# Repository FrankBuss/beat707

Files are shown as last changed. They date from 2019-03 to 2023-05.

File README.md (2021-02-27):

# Development environment

## Programmer and debug connection

For programming you can use an USBasp. The red wire of the USBasp programmer needs to be connected to the `pin 1` location:

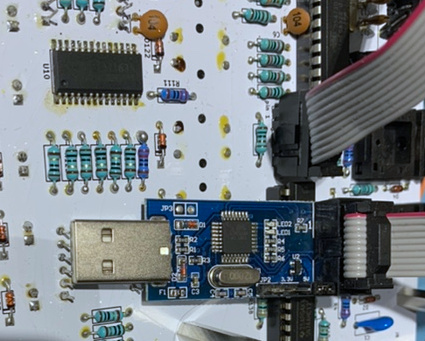
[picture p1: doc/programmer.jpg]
Programmer


For debugging, there is the jumper J5 near the MIDI connector, to connect a 5V UART receiver. Connect the top pin to GND (black wire in the image) and the bottom pin to the UART RX input (grey wire) :

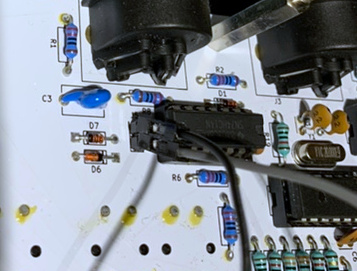
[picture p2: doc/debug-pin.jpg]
debug pin


## Fuse programming

The Arduino IDE doesn't flash the ATmega fuses, so initially you need to do this from the command line with avrdude like this:

```
avrdude -cusbasp -p m328 -B 10 -U lfuse:w:0xff:m
```
The output should look like this:

```
avrdude: set SCK frequency to 93750 Hz
avrdude: AVR device initialized and ready to accept instructions

Reading | ################################################## | 100% 0.00s

avrdude: Device signature = 0x1e9514 (probably m328)
avrdude: reading input file "0xff"
avrdude: writing lfuse (1 bytes):

Writing | ################################################## | 100% 0.00s

avrdude: 1 bytes of lfuse written
avrdude: verifying lfuse memory against 0xff:
avrdude: load data lfuse data from input file 0xff:
avrdude: input file 0xff contains 1 bytes
avrdude: reading on-chip lfuse data:

Reading | ################################################## | 100% 0.00s

avrdude: verifying ...
avrdude: 1 bytes of lfuse verified

avrdude: safemode: Fuses OK (E:FF, H:D9, L:FF)

avrdude done.  Thank you.
```

## Arduino IDE setup

First install the Arduino IDE. It was tested with Arduino 1.8.13. Then add the URL https://mcudude.github.io/MiniCore/package_MCUdude_MiniCore_index.json to "File->Preferences->Settings->Additional Board Manager URLs". Then you can install the new board with "Tools->Board->Boards Manager". Install "MiniCore by MCUdude", tested with version 2.1.0.

For programming you need an USBasp. You need to reduce the clock speed in the file `/home/username/bin/arduino-1.8.9/hardware/arduino/avr/programmers.txt`, where `username` is your username (on Linux, on Windows and Mac it might be different, see [here](https://www.arduino.cc/en/hacking/preferences)). Search for the `usbasp.program.extra_params` line and add the parameter `-B 10`. The full line now looks like this:

```
usbasp.program.extra_params=-Pusb -B 10
```

Restart the Arduino IDE after changing it.

After restart, select the new board: Tools->Board->MiniCore->ATmega328. For flashing the firmware, configure the following settings (Board, Clock, Variant and Bootloader needs to be changed):

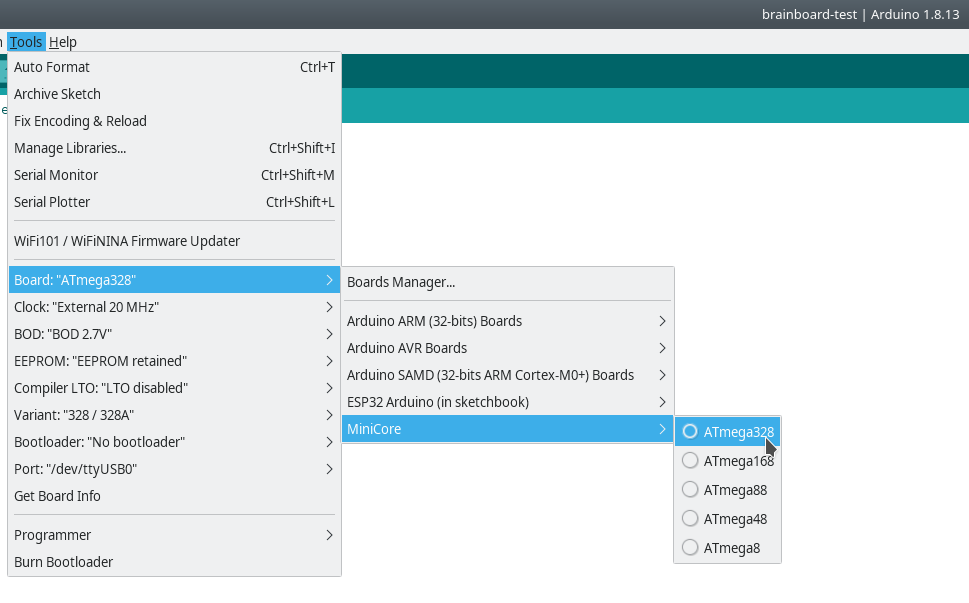
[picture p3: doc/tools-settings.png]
Arduino settings


Then select your programmer, for example USBasp:

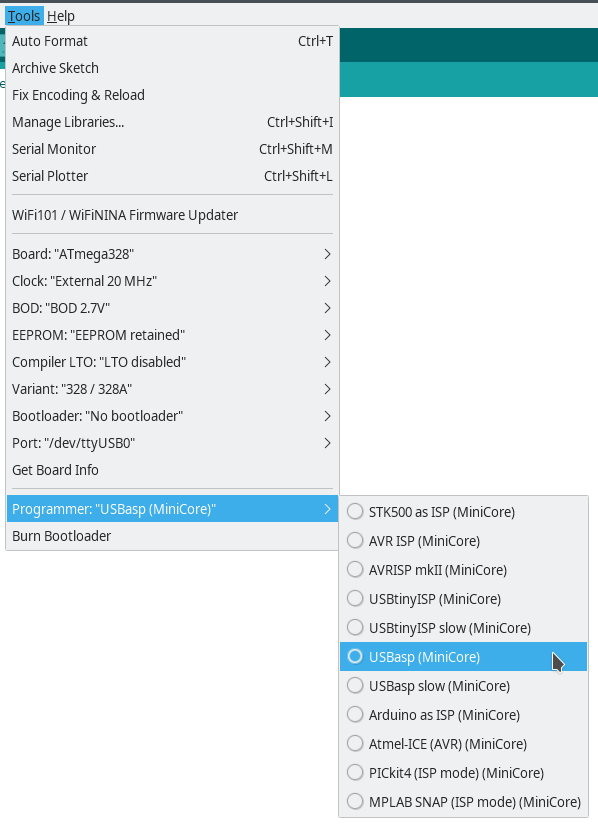
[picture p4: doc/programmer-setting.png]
Prorgammer settings


After this you can program the ATmega328 on the board from the Arduino IDE by clicking on the right arrow.

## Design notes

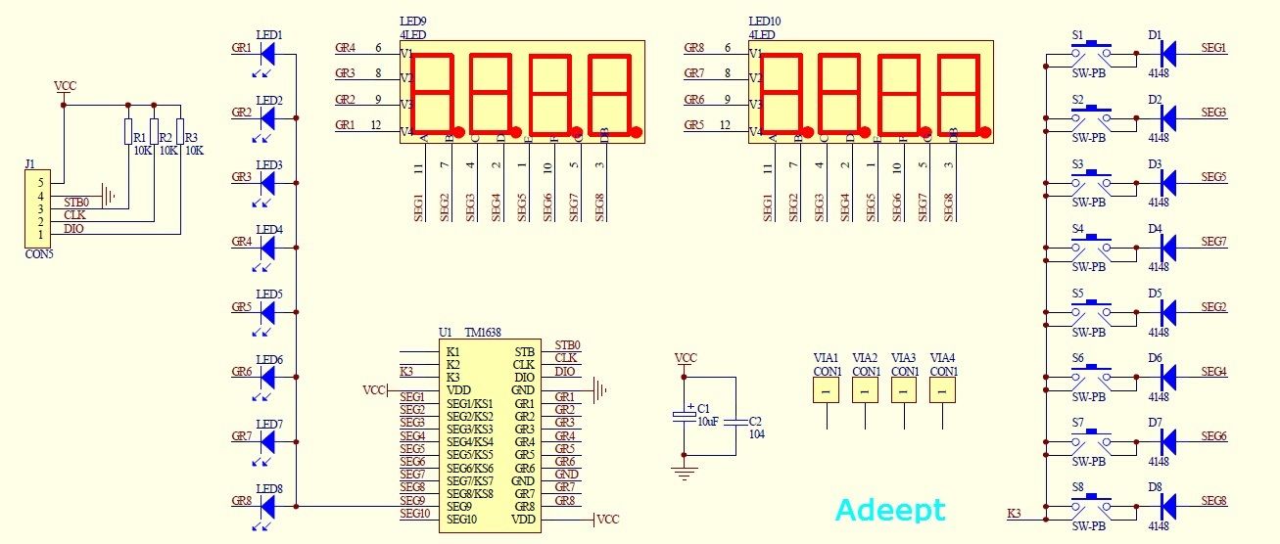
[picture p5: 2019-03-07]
datasheet/tm1638-ebay.jpg

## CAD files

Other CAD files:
kicad/beat707/button.blend
kicad/beat707/din5.blend
kicad/beat707/encoder.blend
kicad/beat707/trs.blend
kicad/beat707/usb.blend

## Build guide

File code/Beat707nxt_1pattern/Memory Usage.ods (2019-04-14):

PATTERN CONFIGURATION
Variable Name | Type | Amount | Bytes |  | Drum Tracks | 10
totalVariations | byte | 1 | 1 |  | Note Tracks | 6
trackProcessor | byte | 16 | 16 |  | Echos | 2
lastNote | byte | 6 | 6
programChange | byte | 16 | 16
sendCC | byte | 16 | 16
sendCCValueLFO | byte | 16 | 16
echoConfig | WECHO | 2 | 10
 |  | Total Bytes | 81
PATTERN STEPS |  |  |  |  | ECHO
Variable Name | Type | Amount | Bytes |  | Variable Name | Type | Amount | Bytes
steps | byte | 160 | 160 |  | track | byte | 1 | 1
stepsDouble | 16 bits | 64 | 128 |  | ticks | byte | 1 | 1
noteSteps | byte | 384 | 384 |  | space | byte | 1 | 1
noteStepsExtras | byte | 192 | 192 |  | type | byte | 1 | 1
 |  | Total Bytes | 864 |  | attackDecay | char | 1 | 1
 |  |  |  |  |  |  | Total Bytes | 5
GLOBAL CONFIGURATION
Variable Name | Type | Amount | Bytes
drumNoteLen | byte | 16 | 16
trackNote | byte | 6 | 6
trackMidiCH | byte | 16 | 16
trackLen | byte | 16 | 16
programChangeOffset | byte | 16 | 16
accentValues | byte | 3 | 3
BPM | byte | 1 | 1
seqSyncOut | bool | 1 | 1
muteTrack | 32 bits | 1 | 4
midiClockInternal | bool | 1 | 1
writeProtectFlash | bool | 1 | 1
tickOut | byte | 1 | 1
tickOutLen | byte | 1 | 1
 |  | Total Bytes | 83
 |  | Total RAM Usage | 1033 | Bytes | * Keep in mind that this does not count variables used to make the program work
 |  |  | 1.01 | Kbytes

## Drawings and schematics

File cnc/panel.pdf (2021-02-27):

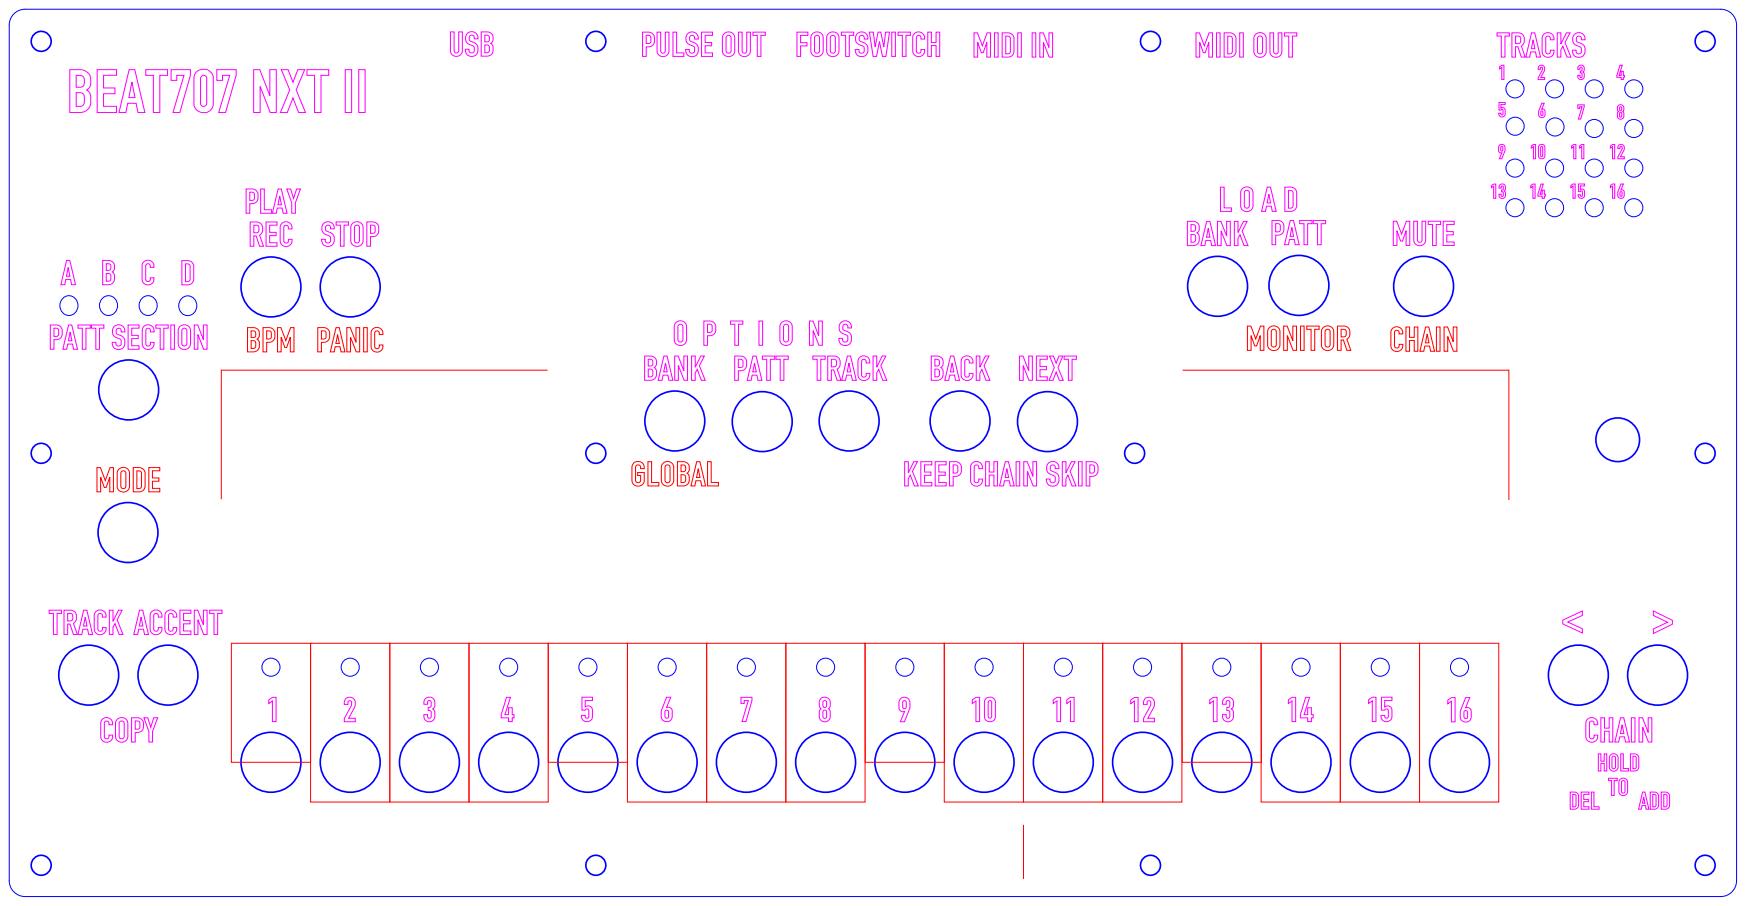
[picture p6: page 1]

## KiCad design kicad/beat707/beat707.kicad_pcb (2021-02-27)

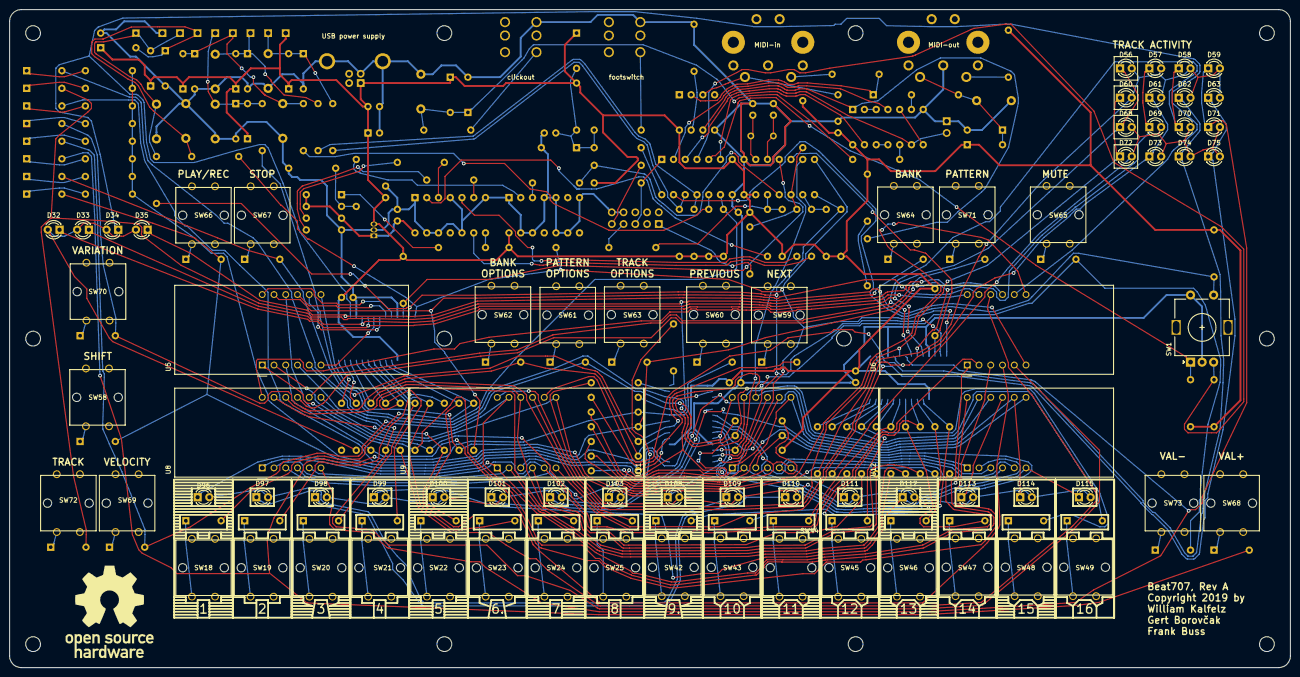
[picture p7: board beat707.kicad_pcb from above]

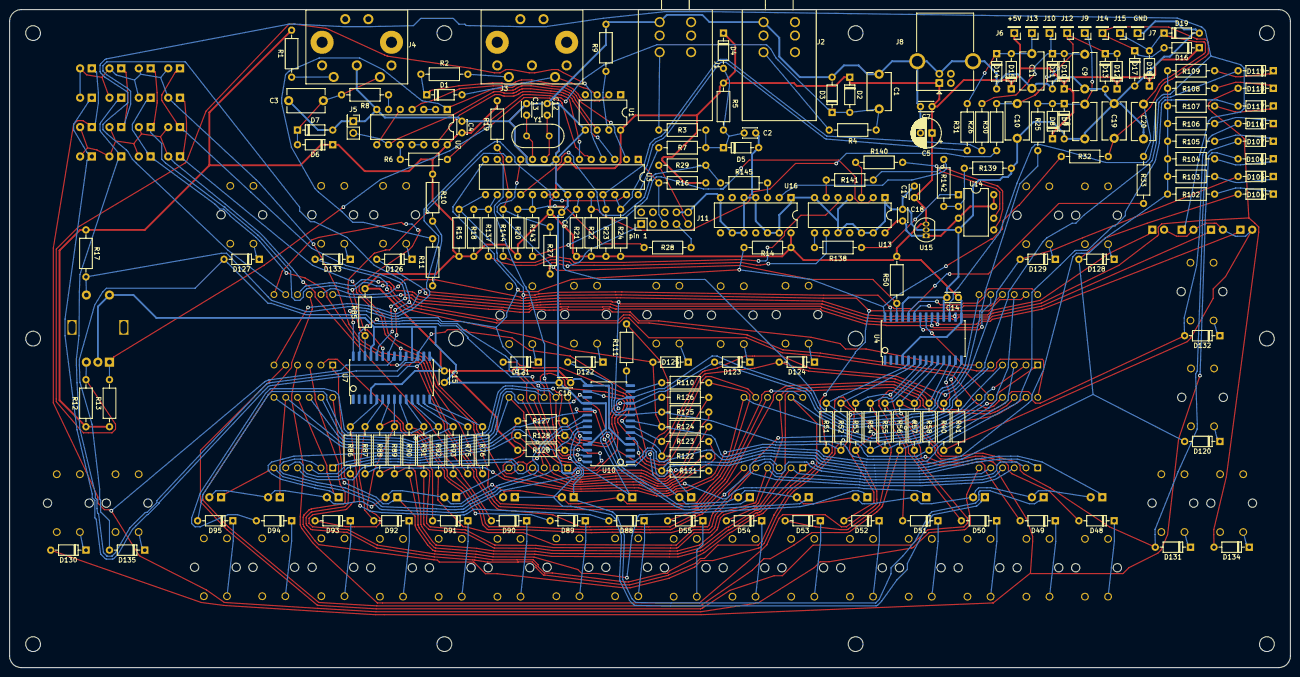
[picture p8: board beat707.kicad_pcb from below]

Board: 2 copper layers, 276.9 x 142.2 mm, 276 parts (188 on the bottom side), 188 nets.

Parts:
C1, C3, C8, C9, C10, C11, C19, C20: 1nF; C_Disc_D8.0mm_W5.0mm_P7.50mm
C2, C4, C6, C7, C14, C15, C16, C17, C18: 100nF; C_Disc_D3.0mm_W2.0mm_P2.50mm
C5: 47uF; CP_Radial_D6.3mm_P2.50mm
C12, C13: 22pF; C_Disc_D3.0mm_W2.0mm_P2.50mm
D1, D2, D3, D4, D5, D6, D7, D8, D9, D10, D11, D12, D13, D14, D15, D16, D17, D18, D19, D48, D49, D50, D51, D52, D53, D54, D55, D88, D89, D90, D91, D92, D93, D94, D95, D104, D105, D106, D107, D116, D117, D118, D119, D120, D121, D122, D123, D124, D125, D126, D127, D128, D129, D130, D131, D132, D133, D134, D135: 1N4148; D_DO-35_SOD27_P7.62mm_Horizontal
D32, D33, D34, D35, D56, D57, D58, D59, D60, D61, D62, D63, D68, D69, D70, D71, D72, D73, D74, D75, D96, D97, D98, D99, D100, D101, D102, D103, D108, D109, D110, D111, D112, D113, D114, D115: LED; LED_D3.0mm
H1, H2, H3, H4, H5, H6, H7, H8, H9, H10, H11, H12: MountingHole; MountingHole_3.2mm_M3
J1: footswitch; trs
J2: click-out; trs
J3: MIDI-in; din-5
J4: MIDI-out; din-5
J5: serial debug; PinHeader_2x01_P2.54mm_Vertical
J6: +5V; PinHeader_1x01_P2.54mm_Vertical
J7: GND; PinHeader_1x01_P2.54mm_Vertical
J8: USB_B; USB_B_OST_USB-B1HSxx_Horizontal
J9, J10, J12, J13, J14, J15: free IO; PinHeader_1x01_P2.54mm_Vertical
J11: ISP; PinHeader_2x05_P2.54mm_Vertical
LOGO1: Logo_Open_Hardware_Small; OSHW-Logo_19x20mm_SilkScreen
R1, R2, R3, R4, R6, R8, R10, R11, R25, R26, R30, R31, R32, R33, R40, R41, R75, R76, R110, R111: 220; R_Axial_DIN0207_L6.3mm_D2.5mm_P10.16mm_Horizontal
R5, R27, R28, R29: 1k; R_Axial_DIN0207_L6.3mm_D2.5mm_P10.16mm_Horizontal
R7, R9, R12, R13, R14, R15, R16, R17, R18, R19, R20, R21, R22, R23, R24, R50, R85, R120, R139: 10k; R_Axial_DIN0207_L6.3mm_D2.5mm_P10.16mm_Horizontal
R51, R52, R53, R54, R55, R56, R57, R58, R86, R87, R88, R89, R90, R91, R92, R93, R121, R122, R123, R124, R125, R126, R127, R128: 10; R_Axial_DIN0207_L6.3mm_D2.5mm_P10.16mm_Horizontal
R102, R103, R104, R105, R106, R107, R108, R109: 0; R_Axial_DIN0207_L6.3mm_D2.5mm_P10.16mm_Horizontal
R137, R138, R140, R141, R142, R143, R144, R145: 33; R_Axial_DIN0207_L6.3mm_D2.5mm_P10.16mm_Horizontal
SW1: Rotary_Encoder_Switch; RotaryEncoder_Alps_EC11E-Switch_Vertical_H20mm
SW18, SW19, SW20, SW21, SW22, SW23, SW24, SW25, SW42, SW43, SW44, SW45, SW46, SW47, SW48, SW49, SW58, SW59, SW60, SW61, SW62, SW63, SW64, SW65, SW66, SW67, SW68, SW69, SW70, SW71, SW72, SW73: SW_Push; B3F-through-hole
U1: 6N138; DIP-8_W7.62mm
U2: 74HC14; DIP-14_W7.62mm
U3: ATmega328-PU; DIP-28_W7.62mm
U4, U7, U10: TM1638; SOIC-28W_7.5x17.9mm_P1.27mm
U5, U6, U8, U9, U11, U12: CA56-12EWA
U13: SN74AHC125; DIP-14_W7.62mm
U14: MB85RS2MT; DIP-8_W7.62mm
U15: LP2950CZ-3.3G; TO-92_Inline
U16: SN74AHCT125; DIP-14_W7.62mm
Y1: 20 MHz; Crystal_HC49-U_Vertical

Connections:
+3V3: C18.2, U13.14, U14.3, U14.7, U14.8, U15.1
+5V: C4.1, C5.1, C6.1, C7.1, C14.1, C15.1, C16.1, C17.1, D2.1, D4.1, D6.1, D8.1, D10.1, D12.1, D14.1, D16.1, D18.1, J6.1, J8.1, R1.2, R5.2, R10.1, R12.1, R13.1, R14.2, R15.2, R16.1, R17.1, R18.2, R19.2, R20.2, R21.2, R22.2, R23.2, R24.2, R50.2, R85.2, R120.2, U1.8, U2.14, U3.7, U3.20, U3.21, U4.4, U4.15, U7.4, U7.15, U10.4, U10.15, U15.3, U16.14
/TM1638 Module/GRID1: U4.24, U5.12
/TM1638 Module/GRID2: U4.23, U5.9
/TM1638 Module/GRID3: U4.22, U5.8
/TM1638 Module/GRID4: U4.21, U5.6
/TM1638 Module/GRID5: D32.1, U4.20, U6.12
/TM1638 Module/GRID6: D33.1, U4.19, U6.9
/TM1638 Module/GRID7: D34.1, U4.17, U6.8
/TM1638 Module/GRID8: D35.1, U4.16, U6.6
/TM1638 Module/SEG1: D48.2, R51.2, U4.5
/TM1638 Module/SEG2: D52.2, R52.2, U4.6
/TM1638 Module/SEG3: D49.2, R53.2, U4.7
/TM1638 Module/SEG4: D53.2, R54.2, U4.8
/TM1638 Module/SEG5: D50.2, R55.2, U4.9
/TM1638 Module/SEG6: D54.2, R56.2, U4.10
/TM1638 Module/SEG7: D51.2, R57.2, U4.11
/TM1638 Module/SEG8: D55.2, R58.2, U4.12
/memory-module/CS: R18.1, R137.2, U3.16
/sheet5C6557AC/GRID1: D56.1, D68.1, U7.24, U8.12
/sheet5C6557AC/GRID2: D57.1, D69.1, U7.23, U8.9
/sheet5C6557AC/GRID3: D58.1, D70.1, U7.22, U8.8
/sheet5C6557AC/GRID4: D59.1, D71.1, U7.21, U8.6
/sheet5C6557AC/GRID5: D60.1, D72.1, U7.20, U9.12
/sheet5C6557AC/GRID6: D61.1, D73.1, U7.19, U9.9
/sheet5C6557AC/GRID7: D62.1, D74.1, U7.17, U9.8
/sheet5C6557AC/GRID8: D63.1, D75.1, U7.16, U9.6
/sheet5C6557AC/SEG1: D88.2, R86.2, U7.5
/sheet5C6557AC/SEG2: D92.2, R87.2, U7.6
/sheet5C6557AC/SEG3: D89.2, R88.2, U7.7
/sheet5C6557AC/SEG4: D93.2, R89.2, U7.8
/sheet5C6557AC/SEG5: D90.2, R90.2, U7.9
/sheet5C6557AC/SEG6: D94.2, R91.2, U7.10
/sheet5C6557AC/SEG7: D91.2, R92.2, U7.11
/sheet5C6557AC/SEG8: D95.2, R93.2, U7.12
/sheet5C6559D3/GRID1: D96.1, D108.1, U10.24, U11.12
/sheet5C6559D3/GRID2: D97.1, D109.1, U10.23, U11.9
/sheet5C6559D3/GRID3: D98.1, D110.1, U10.22, U11.8
/sheet5C6559D3/GRID4: D99.1, D111.1, U10.21, U11.6
/sheet5C6559D3/GRID5: D100.1, D112.1, U10.20, U12.12
/sheet5C6559D3/GRID6: D101.1, D113.1, U10.19, U12.9
/sheet5C6559D3/GRID7: D102.1, D114.1, U10.17, U12.8
/sheet5C6559D3/GRID8: D103.1, D115.1, U10.16, U12.6
/sheet5C6559D3/K1: R102.2, R103.2, R104.2, R105.2, R106.2, R107.2, R108.2, R109.2, U10.1
/sheet5C6559D3/SEG1: D104.2, D120.2, D128.2, R121.2, U10.5
/sheet5C6559D3/SEG2: D116.2, D124.2, D132.2, R122.2, U10.6
/sheet5C6559D3/SEG3: D105.2, D121.2, D129.2, R123.2, U10.7
/sheet5C6559D3/SEG4: D117.2, D125.2, D133.2, R124.2, U10.8
/sheet5C6559D3/SEG5: D106.2, D122.2, D130.2, R125.2, U10.9
/sheet5C6559D3/SEG6: D118.2, D126.2, D134.2, R126.2, U10.10
/sheet5C6559D3/SEG7: D107.2, D123.2, D131.2, R127.2, U10.11
/sheet5C6559D3/SEG8: D119.2, D127.2, D135.2, R128.2, U10.12
GND: C1.1, C2.1, C3.1, C4.2, C5.2, C6.2, C7.2, C8.1, C9.1, C10.1, C11.1, C12.1, C13.1, C14.2, C15.2, C16.2, C17.2, C18.1, C19.1, C20.1, D3.2, D5.2, D7.2, D9.2, D11.2, D13.2, D15.2, D17.2, D19.2, J1.S, J2.S, J4.2, J5.1, J7.1, J8.4, J8.5, J11.8, J11.10, R9.2, R139.1, SW1.C, SW1.S2, U1.5, U2.7, U3.8, U3.22, U4.18, U4.25, U7.18, U7.25, U10.18, U10.25, U13.1, U13.4, U13.7, U13.10, U13.12, U13.13, U14.4, U15.2, U16.1, U16.4, U16.5, U16.7, U16.9, U16.10, U16.12, U16.13
MIDI-in: U2.4, U3.2
MIDI-out: J5.2, U2.9, U3.3
MISO: R29.2, R145.1, U3.18
MOSI: R19.1, R27.2, R144.1, U3.17
unnamed: D32.2, D33.2, D34.2, D35.2, R40.2
unnamed: C1.2, D2.2, D3.1, R4.1, R6.2
unnamed: C2.2, D4.2, D5.1, R3.1, R5.1, R7.2
unnamed: C3.2, D6.2, D7.1, J4.5, R8.2
unnamed: C8.2, D8.2, D9.1, J9.1, R25.2
unnamed: C9.2, D10.2, D11.1, J10.1, R26.2
unnamed: C10.2, D12.2, D13.1, J12.1, R30.2
unnamed: C11.2, D14.2, D15.1, J13.1, R31.2
unnamed: C12.2, U3.9, Y1.2
unnamed: C13.2, U3.10, Y1.1
unnamed: C19.2, D16.2, D17.1, J14.1, R32.2
unnamed: C20.2, D18.2, D19.1, J15.1, R33.2
unnamed: D1.1, R2.1, U1.2
unnamed: D1.2, J3.5, U1.3
unnamed: D48.1, SW18.4
unnamed: D49.1, SW19.4
unnamed: D50.1, SW20.4
unnamed: D51.1, SW21.4
unnamed: D52.1, SW22.4
unnamed: D53.1, SW23.4
unnamed: D54.1, SW24.4
unnamed: D55.1, SW25.4
unnamed: D56.2, D57.2, D58.2, D59.2, D60.2, D61.2, D62.2, D63.2, R76.2
unnamed: D68.2, D69.2, D70.2, D71.2, D72.2, D73.2, D74.2, D75.2, R75.2
unnamed: D88.1, SW42.4
unnamed: D89.1, SW43.4
unnamed: D90.1, SW44.4
unnamed: D91.1, SW45.4
unnamed: D92.1, SW46.4
unnamed: D93.1, SW47.4
unnamed: D94.1, SW48.4
unnamed: D95.1, SW49.4
unnamed: D96.2, D97.2, D98.2, D99.2, D100.2, D101.2, D102.2, D103.2, R111.2
unnamed: D104.1, R102.1
unnamed: D105.1, R103.1
unnamed: D106.1, R104.1
unnamed: D107.1, R105.1
unnamed: D108.2, D109.2, D110.2, D111.2, D112.2, D113.2, D114.2, D115.2, R110.2
unnamed: D116.1, R106.1
unnamed: D117.1, R107.1
unnamed: D118.1, R108.1
unnamed: D119.1, R109.1
unnamed: D120.1, SW58.4
unnamed: D121.1, SW59.4
unnamed: D122.1, SW60.4
unnamed: D123.1, SW61.4
unnamed: D124.1, SW62.4
unnamed: D125.1, SW63.4
unnamed: D126.1, SW64.4
unnamed: D127.1, SW65.4
unnamed: D128.1, SW66.4
unnamed: D129.1, SW67.4
unnamed: D130.1, SW68.4
unnamed: D131.1, SW69.4
unnamed: D132.1, SW70.4
unnamed: D133.1, SW71.4
unnamed: D134.1, SW72.4
unnamed: D135.1, SW73.4
unnamed: J1.T, R3.2
unnamed: J2.T, R4.2
unnamed: J3.4, R2.2
unnamed: J4.4, R1.1
unnamed: J11.1, R27.1
unnamed: J11.7, R28.1
unnamed: J11.9, R29.1
unnamed: R6.1, U2.10
unnamed: R8.1, U2.6
unnamed: R9.1, U1.7
unnamed: R10.2, R11.1
unnamed: R11.2, U1.6, U2.1
unnamed: R12.2, SW1.B, U3.4
unnamed: R13.2, SW1.A, U3.5
unnamed: R17.2, SW1.S1, U3.27
unnamed: R21.1, R25.1, U3.23
unnamed: R22.1, R30.1, U3.24
unnamed: R23.1, R26.1, U3.25
unnamed: R24.1, R31.1, U3.26
unnamed: R40.1, U4.13
unnamed: R41.1, U4.14
unnamed: R51.1, U5.11, U6.11
unnamed: R52.1, U5.7, U6.7
unnamed: R53.1, U5.4, U6.4
unnamed: R54.1, U5.2, U6.2
unnamed: R55.1, U5.1, U6.1
unnamed: R56.1, U5.10, U6.10
unnamed: R57.1, U5.5, U6.5
unnamed: R58.1, U5.3, U6.3
unnamed: R75.1, U7.13
unnamed: R76.1, U7.14
unnamed: R86.1, U8.11, U9.11
unnamed: R87.1, U8.7, U9.7
unnamed: R88.1, U8.4, U9.4
unnamed: R89.1, U8.2, U9.2
unnamed: R90.1, U8.1, U9.1
unnamed: R91.1, U8.10, U9.10
unnamed: R92.1, U8.5, U9.5
unnamed: R93.1, U8.3, U9.3
unnamed: R110.1, U10.13
unnamed: R111.1, U10.14
unnamed: R121.1, U11.11, U12.11
unnamed: R122.1, U11.7, U12.7
unnamed: R123.1, U11.4, U12.4
unnamed: R124.1, U11.2, U12.2
unnamed: R125.1, U11.1, U12.1
unnamed: R126.1, U11.10, U12.10
unnamed: R127.1, U11.5, U12.5
unnamed: R128.1, U11.3, U12.3
unnamed: R137.1, U13.9
unnamed: R138.1, U14.1
unnamed: R138.2, U13.8
unnamed: R139.2, R142.2, U14.2
unnamed: R140.1, U13.3
unnamed: R140.2, U14.6
unnamed: R141.1, U13.6
unnamed: R141.2, U14.5
unnamed: R142.1, U16.2
unnamed: R143.2, U13.2
unnamed: R144.2, U13.5
unnamed: R145.2, U16.3
unnamed: U2.2, U2.3
unnamed: U2.5, U2.8
unnamed: U2.11, U2.12
RESET: J11.5, R16.2, U3.1
SCK: R20.1, R28.2, R143.1, U3.19
click-out: U2.13, U3.6
footswitch: R7.1, U3.28
tm1638-clk: R15.1, R33.1, U3.15, U4.27, U7.27, U10.27
tm1638-dio-1: R50.1, U3.11, U4.26
tm1638-dio-2: R85.1, U3.12, U7.26
tm1638-dio-3: R120.1, U3.13, U10.26
tm1638-stb: R14.1, R32.1, U3.14, U4.28, U7.28, U10.28

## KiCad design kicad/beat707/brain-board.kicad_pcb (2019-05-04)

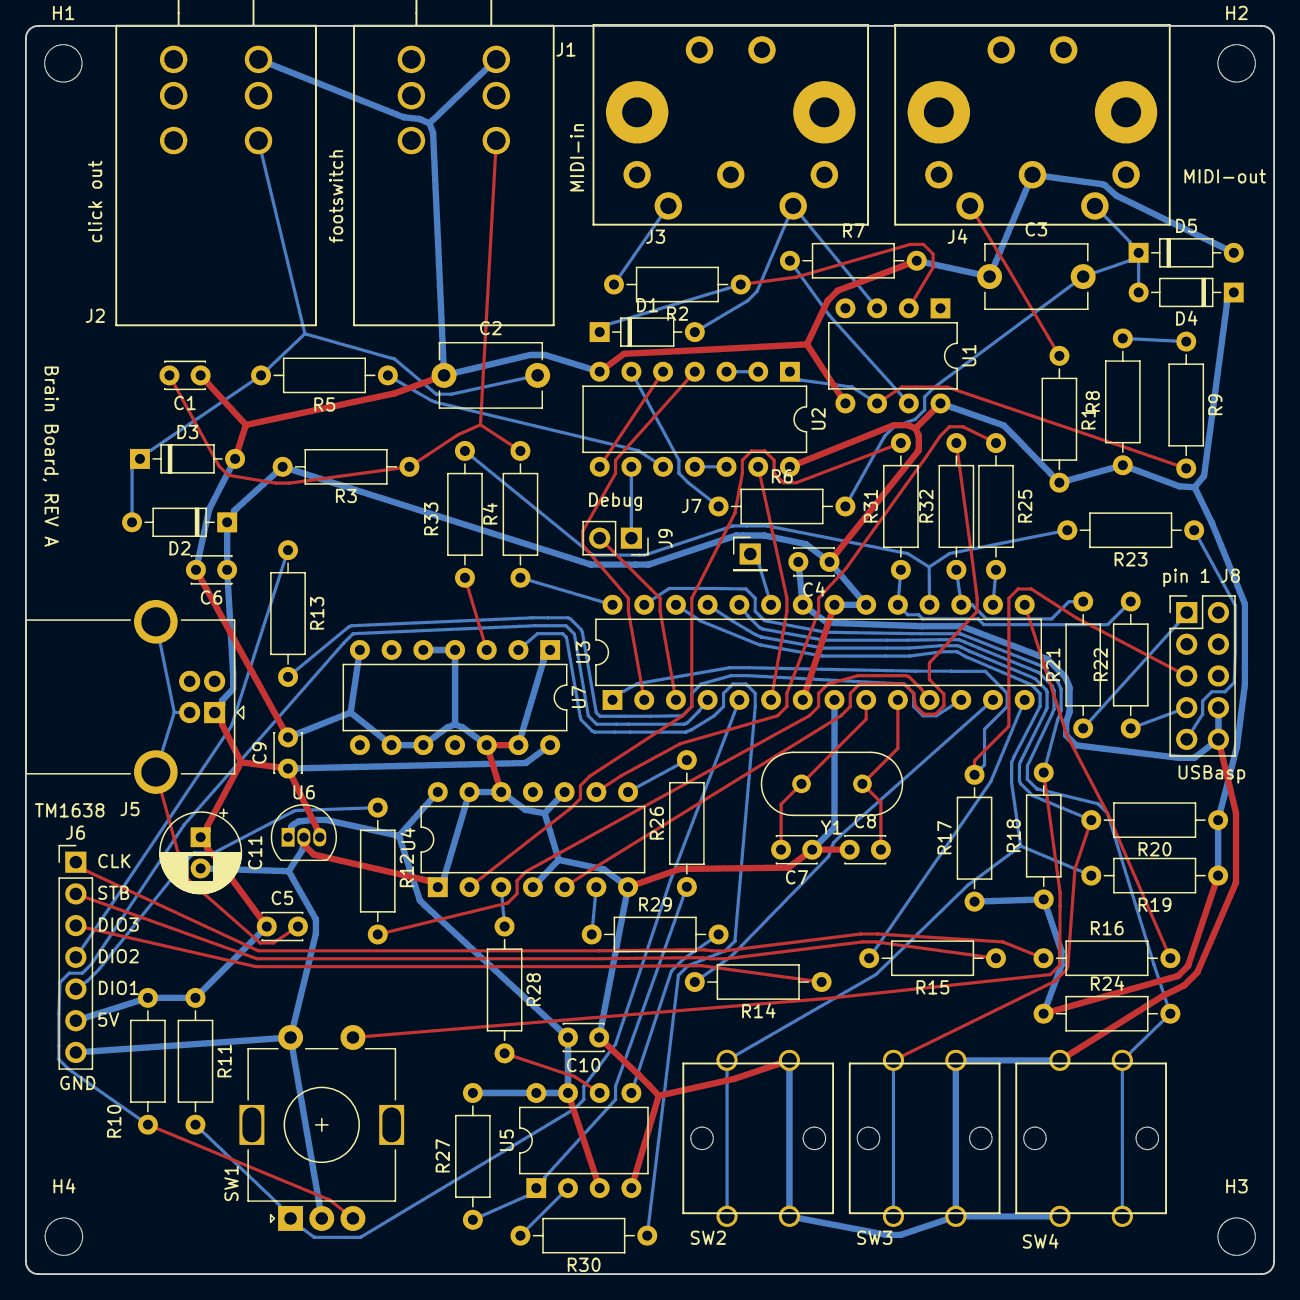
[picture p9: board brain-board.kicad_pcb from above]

Board: 2 copper layers, 100.0 x 100.0 mm, 74 parts (0 on the bottom side), 63 nets.

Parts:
C1, C4, C5, C6, C9, C10: 100nF; C_Disc_D3.0mm_W2.0mm_P2.50mm
C2, C3: 1nF; C_Disc_D8.0mm_W5.0mm_P7.50mm
C7, C8: 22pF; C_Disc_D3.0mm_W2.0mm_P2.50mm
C11: 10uF; CP_Radial_D6.3mm_P2.50mm
D1, D2, D3, D4, D5: 1N4148; D_DO-35_SOD27_P7.62mm_Horizontal
H1, H2, H3, H4: MountingHole; MountingHole_3mm
J1: footswitch; trs
J2: click-out; trs
J3: MIDI-in; din-5
J4: MIDI-out; din-5
J5: USB_B; USB_B_OST_USB-B1HSxx_Horizontal
J6: Conn_01x07; PinHeader_1x07_P2.54mm_Vertical
J7: free IO; PinHeader_1x01_P2.54mm_Vertical
J8: ISP; PinHeader_2x05_P2.54mm_Vertical
J9: Conn_01x02_Male; PinSocket_1x02_P2.54mm_Vertical
R1, R2, R5, R6, R8, R9: 220; R_Axial_DIN0207_L6.3mm_D2.5mm_P10.16mm_Horizontal
R3, R21, R22, R23: 1k; R_Axial_DIN0207_L6.3mm_D2.5mm_P10.16mm_Horizontal
R4, R7, R10, R11, R17, R18, R19, R20, R24, R27: 10k; R_Axial_DIN0207_L6.3mm_D2.5mm_P10.16mm_Horizontal
R12, R13, R14, R15, R16, R25, R26, R28, R29, R30, R31, R32, R33: 33; R_Axial_DIN0207_L6.3mm_D2.5mm_P10.16mm_Horizontal
SW1: Rotary_Encoder_Switch; RotaryEncoder_Alps_EC11E-Switch_Vertical_H20mm
SW2, SW3, SW4: SW_Push; B3F-through-hole
U1: 6N138; DIP-8_W7.62mm
U2: 74HC14; DIP-14_W7.62mm
U3: ATmega328-PU; DIP-28_W7.62mm
U4: SN74AHC125; DIP-14_W7.62mm
U5: MB85RS2MT; DIP-8_W7.62mm
U6: LP2950CZ-3.3G; TO-92_Inline
U7: SN74AHCT125; DIP-14_W7.62mm
Y1: 20 MHz; Crystal_HC49-U_Vertical

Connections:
+3V3: C10.2, R27.2, U4.14, U5.3, U5.7, U5.8, U6.1
+5V: C4.1, C5.1, C6.1, C9.1, C11.1, D2.1, D4.1, J5.1, J6.6, R1.2, R3.2, R8.1, R10.1, R11.1, R17.1, R18.1, R19.1, R20.1, R24.1, U1.8, U2.14, U3.7, U3.20, U3.21, U6.3, U7.14
/memory-module/CS: R25.2, U3.16
GND: C1.1, C2.1, C3.1, C4.2, C6.2, C7.1, C8.1, C9.2, C10.1, C11.2, D3.2, D5.2, J1.S, J2.S, J4.2, J6.7, J8.8, J8.10, R7.2, SW1.C, SW1.S2, SW2.3, SW2.4, SW3.3, SW3.4, SW4.3, SW4.4, U1.5, U2.7, U3.8, U3.22, U4.1, U4.4, U4.7, U4.10, U4.12, U4.13, U5.4, U6.2, U7.1, U7.4, U7.5, U7.7, U7.9, U7.10, U7.12, U7.13
MIDI-in: U2.4, U3.2
MIDI-out: J9.2, U3.3
MISO: R23.2, R33.1, U3.18
MOSI: R21.2, R32.1, U3.17
unnamed: C1.2, J1.T, R3.1, R4.2
unnamed: C2.2, D2.2, D3.1, J2.T, R5.2
unnamed: C3.2, D4.2, D5.1, J4.5, R6.2
unnamed: C5.2, J5.4, J5.5
unnamed: C7.2, U3.9, Y1.2
unnamed: C8.2, U3.10, Y1.1
unnamed: D1.1, R2.1, U1.2
unnamed: D1.2, J3.5, U1.3
unnamed: J3.4, R2.2
unnamed: J4.4, R1.1
unnamed: J7.1, U3.23
unnamed: J8.1, R21.1
unnamed: J8.7, R22.1
unnamed: J8.9, R23.1
unnamed: J9.1, U2.9
unnamed: R5.1, U2.10
unnamed: R6.1, U2.6
unnamed: R7.1, U1.7
unnamed: R8.2, R9.1
unnamed: R9.2, U1.6, U2.1
unnamed: R10.2, SW1.B, U3.4
unnamed: R11.2, SW1.A, U3.5
unnamed: R12.2, U3.11
unnamed: R13.2, U3.12
unnamed: R14.2, U3.13
unnamed: R15.2, U3.14
unnamed: R16.2, U3.15
unnamed: R18.2, SW1.S1, U3.27
unnamed: R19.2, SW2.1, SW2.2, U3.26
unnamed: R20.2, SW3.1, SW3.2, U3.25
unnamed: R24.2, SW4.1, SW4.2, U3.24
unnamed: R25.1, U4.9
unnamed: R26.1, R27.1, U5.1
unnamed: R26.2, U4.8
unnamed: R28.1, U4.3
unnamed: R28.2, U5.6
unnamed: R29.1, U4.6
unnamed: R29.2, U5.5
unnamed: R30.1, U7.2
unnamed: R30.2, U5.2
unnamed: R31.2, U4.2
unnamed: R32.2, U4.5
unnamed: R33.2, U7.3
unnamed: U2.2, U2.3
unnamed: U2.5, U2.8
unnamed: U2.11, U2.12
RESET: J8.5, R17.2, U3.1
SCK: R22.2, R31.1, U3.19
click-out: U2.13, U3.6
footswitch: R4.1, U3.28
tm1638-clk: J6.1, R16.1
tm1638-dio-1: J6.5, R12.1
tm1638-dio-2: J6.4, R13.1
tm1638-dio-3: J6.3, R14.1
tm1638-stb: J6.2, R15.1

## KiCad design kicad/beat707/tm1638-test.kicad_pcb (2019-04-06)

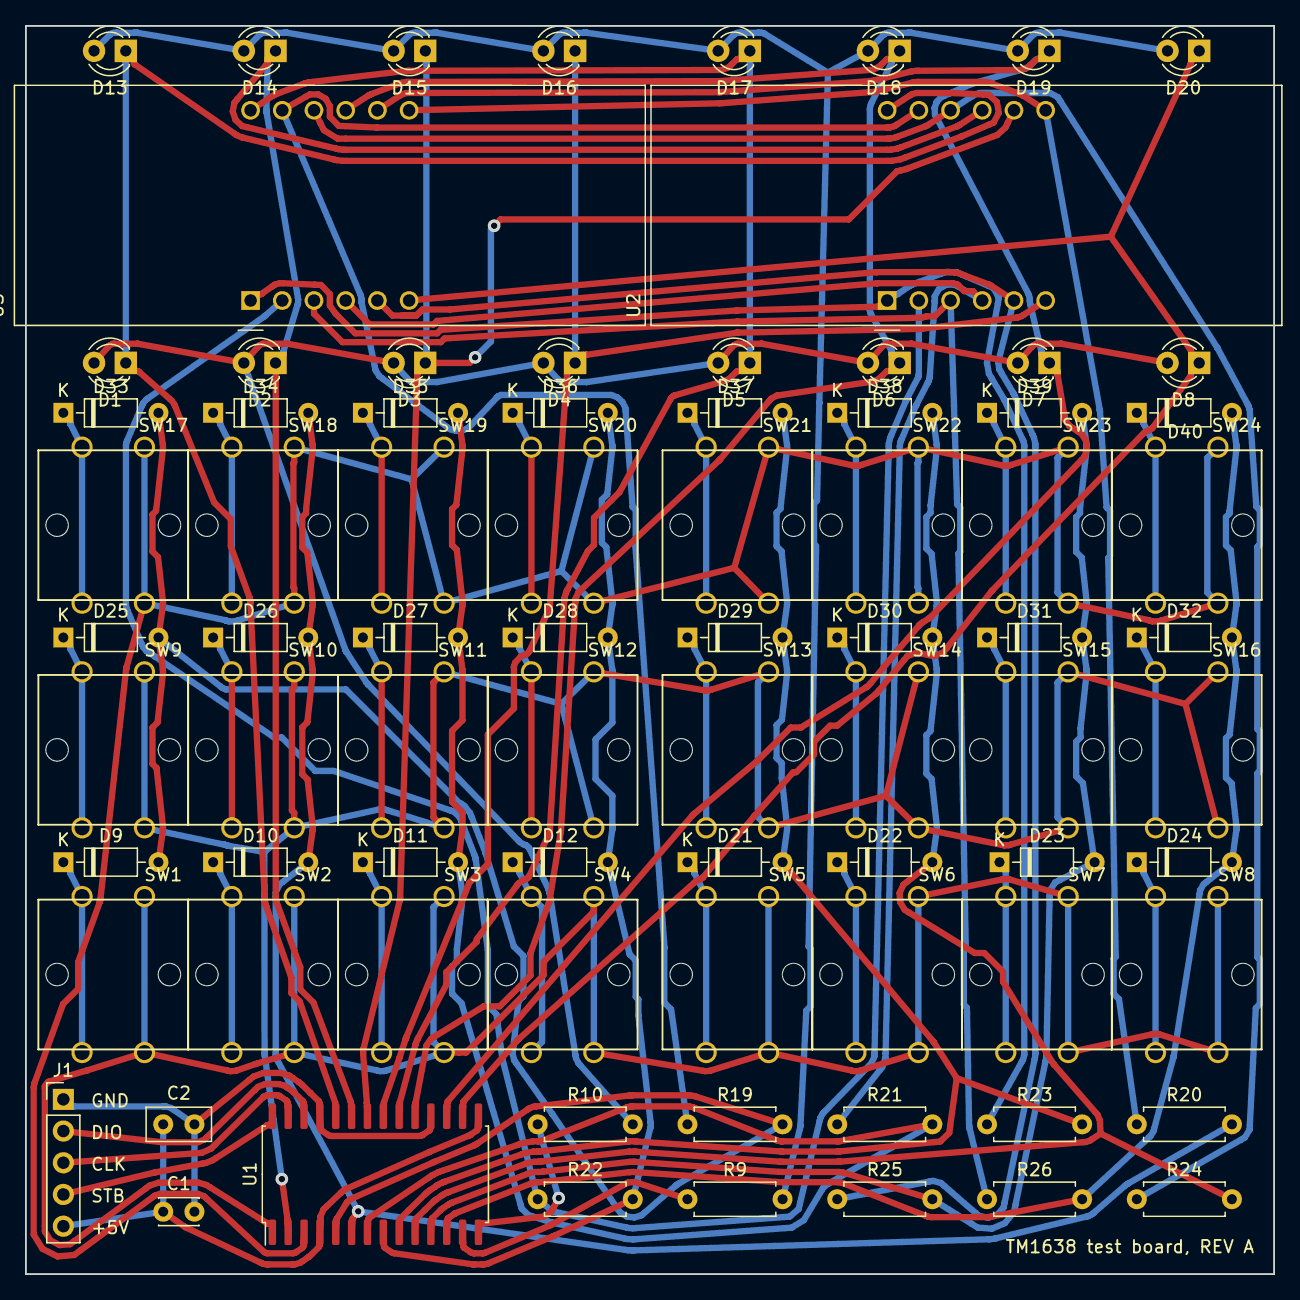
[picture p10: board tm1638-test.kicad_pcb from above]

Board: 2 copper layers, 100.0 x 100.0 mm, 80 parts (0 on the bottom side), 60 nets.

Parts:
C1: 100nF; C_Disc_D3.0mm_W2.0mm_P2.50mm
C2: 10uF; C_Disc_D5.0mm_W2.5mm_P2.50mm
D1, D2, D3, D4, D5, D6, D7, D8, D13, D14, D15, D16, D17, D18, D19, D20: LED; LED_D3.0mm
D9, D10, D11, D12, D21, D22, D23, D24, D25, D26, D27, D28, D29, D30, D31, D32, D33, D34, D35, D36, D37, D38, D39, D40: 1N4148; D_DO-35_SOD27_P7.62mm_Horizontal
J1: Conn_01x05_Male; PinHeader_1x05_P2.54mm_Vertical
R9, R10, R19, R20, R21, R22, R23, R24, R25, R26: 51; R_Axial_DIN0207_L6.3mm_D2.5mm_P7.62mm_Horizontal
SW1, SW2, SW3, SW4, SW5, SW6, SW7, SW8, SW9, SW10, SW11, SW12, SW13, SW14, SW15, SW16, SW17, SW18, SW19, SW20, SW21, SW22, SW23, SW24: SW_Push; B3F-through-hole
U1: TM1638; SOIC-28W_7.5x17.9mm_P1.27mm
U2, U3: CA56-12EWA

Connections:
+5V: C1.1, C2.1, J1.5, U1.4, U1.15
/TM1638 Module/CLK: J1.3, U1.27
/TM1638 Module/DIO: J1.2, U1.26
/TM1638 Module/GRID1: D1.1, D13.1, U1.24, U2.12
/TM1638 Module/GRID2: D2.1, D14.1, U1.23, U2.9
/TM1638 Module/GRID3: D3.1, D15.1, U1.22, U2.8
/TM1638 Module/GRID4: D4.1, D16.1, U1.21, U2.6
/TM1638 Module/GRID5: D5.1, D17.1, U1.20, U3.12
/TM1638 Module/GRID6: D6.1, D18.1, U1.19, U3.9
/TM1638 Module/GRID7: D7.1, D19.1, U1.17, U3.8
/TM1638 Module/GRID8: D8.1, D20.1, U1.16, U3.6
/TM1638 Module/K1: SW1.1, SW1.2, SW2.1, SW2.2, SW3.1, SW3.2, SW4.1, SW4.2, SW5.1, SW5.2, SW6.1, SW6.2, SW7.1, SW7.2, SW8.1, SW8.2, U1.1
/TM1638 Module/K2: SW9.1, SW9.2, SW10.1, SW10.2, SW11.1, SW11.2, SW12.1, SW12.2, SW13.1, SW13.2, SW14.1, SW14.2, SW15.1, SW15.2, SW16.1, SW16.2, U1.2
/TM1638 Module/K3: SW17.1, SW17.2, SW18.1, SW18.2, SW19.1, SW19.2, SW20.1, SW20.2, SW21.1, SW21.2, SW22.1, SW22.2, SW23.1, SW23.2, SW24.1, SW24.2, U1.3
/TM1638 Module/SEG1: D9.2, D25.2, D33.2, R19.2, U1.5
/TM1638 Module/SEG2: D10.2, D26.2, D34.2, R20.2, U1.6
/TM1638 Module/SEG3: D11.2, D27.2, D35.2, R21.2, U1.7
/TM1638 Module/SEG4: D12.2, D28.2, D36.2, R22.2, U1.8
/TM1638 Module/SEG5: D21.2, D29.2, D37.2, R23.2, U1.9
/TM1638 Module/SEG6: D22.2, D30.2, D38.2, R24.2, U1.10
/TM1638 Module/SEG7: D23.2, D31.2, D39.2, R25.2, U1.11
/TM1638 Module/SEG8: D24.2, D32.2, D40.2, R26.2, U1.12
/TM1638 Module/STB: J1.4, U1.28
GND: C1.2, C2.2, J1.1, U1.18, U1.25
unnamed: D1.2, D2.2, D3.2, D4.2, D5.2, D6.2, D7.2, D8.2, R10.2
unnamed: D9.1, SW1.3, SW1.4
unnamed: D10.1, SW2.3, SW2.4
unnamed: D11.1, SW3.3, SW3.4
unnamed: D12.1, SW4.3, SW4.4
unnamed: D13.2, D14.2, D15.2, D16.2, D17.2, D18.2, D19.2, D20.2, R9.2
unnamed: D21.1, SW5.3, SW5.4
unnamed: D22.1, SW6.3, SW6.4
unnamed: D23.1, SW7.3, SW7.4
unnamed: D24.1, SW8.3, SW8.4
unnamed: D25.1, SW9.3, SW9.4
unnamed: D26.1, SW10.3, SW10.4
unnamed: D27.1, SW11.3, SW11.4
unnamed: D28.1, SW12.3, SW12.4
unnamed: D29.1, SW13.3, SW13.4
unnamed: D30.1, SW14.3, SW14.4
unnamed: D31.1, SW15.3, SW15.4
unnamed: D32.1, SW16.3, SW16.4
unnamed: D33.1, SW17.3, SW17.4
unnamed: D34.1, SW18.3, SW18.4
unnamed: D35.1, SW19.3, SW19.4
unnamed: D36.1, SW20.3, SW20.4
unnamed: D37.1, SW21.3, SW21.4
unnamed: D38.1, SW22.3, SW22.4
unnamed: D39.1, SW23.3, SW23.4
unnamed: D40.1, SW24.3, SW24.4
unnamed: R9.1, U1.13
unnamed: R10.1, U1.14
unnamed: R19.1, U2.11, U3.11
unnamed: R20.1, U2.7, U3.7
unnamed: R21.1, U2.4, U3.4
unnamed: R22.1, U2.2, U3.2
unnamed: R23.1, U2.1, U3.1
unnamed: R24.1, U2.10, U3.10
unnamed: R25.1, U2.5, U3.5
unnamed: R26.1, U2.3, U3.3

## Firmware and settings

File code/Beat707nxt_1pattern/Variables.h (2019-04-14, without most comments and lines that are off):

#define DEFAULT_NOTE 36       // When adding a new note the default note value for the very first note - Set to 0 so it asks what is the default note everytime you add the first one on a pattern
#define DEFAULT_MIDI_CH 10    // MIDI Channel for all tracks: 1 ~ 16
#define DRUM_TRACKS 10        // This can't go above 16
#define NOTE_TRACKS 5         // This can't go above 8
#define PATTERNS 16           // This can't go above 64
#define PT_BANKS 16           // # of Pattern Banks - should be the MAX that the Winbond chip can take (usually 28)
#define ECHOS 1               // Depends on RAM left, usually can't go above 9
#define STEPS 16              // This can't go above 16
#define TEMPORARY_MESSAGE_TIME 80
#define EXTERNAL_CLOCK_TIMER (F_CPU / 3960) // Timer speed used to read the External MIDI Clock - MIDI is 31250 bauds = 3906 bytes per second
#define MIDI_INPUT_BUFFER (4 * 2) // The size of the internal buffer used for recording
#define DEBUG_MIDI_BUFFER_SIZE 512
enum
{
  fadeIn = 1, fadeOut, randomVel,
  kButtonNone = 0, kButtonClicked, kButtonHold, kButtonRelease, kButtonReleaseNothingClicked,
  kRightSteps = 0, kRightABCDVariations, kRightTrackSelection, kRightMenuCopyPaste, kRightMenu, kMuteMenu,
  midiNoteOn = 0x90, midiNoteOff = 0x80, midiCC = 0xB0, midiProgramChange = 0xC0, midiChannels = 16,
  echoTypeOnAllNotes = 0, echoTypeForceMaxVelocity, echoTypeForceLowVelocity,
  midiCCLFO = 7,
  procFadeMin = 4,
  menuFirst = 0,
      menuMIDIChannel = 0,
      menuTrackLen,
      menuPCOffset,
      menuNote,
      menuNoteLen,
      menuAccent1,
      menuAccent2,
      menuAccent3,
      menuVariationsABCD,
      menuProc,
      menuEcho,
      menuEchoTrack,
      menuEchoTicks,
      menuEchoSpace,
      menuEchoAttackDecay,
      menuEchoType,
      menuClockType,
      menuSyncOut,
      menuProtect,
      menuProgramChange,
      menuMIDICC,
      menuMIDICCLFO,
      menuMIDICCValueRate,
      menuPulseOut,
      menuPulseOutLen,
      menuInit,
        lastMenu = menuInit,
  kLeftMain = 0,
  kMemoryProtectMessage = 0, kPatternRepeatMessage, kVersionNumberMessage,
  kRepeatModeNormal = 0, kRepeatModeChain, kRepeatModePattern
};
byte segments[3][8];
byte leds[3];
byte buttons[3]; // raw button values
byte buttonEvent[3][8];
byte buttonEventWasHolding[3] = {0, 0, 0};
byte buttonIsHolding[8];
byte buttonDownTime[3][8]; // time of the button press
byte variation = 0; // ABCD Variations
char forceVariation = -1;
byte curTrack = 0;
bool updateScreen = true;
byte curLeftScreen = 0;
byte curRightScreen = 0;
bool mirror = true;
bool somethingClicked = false;
bool somethingHappened = false;
bool forceAccent = false;
bool showBPMdot = false;
bool showBPMdotBuffer = false;
bool seqPlaying = false;
byte seqPosition = 0;
byte seqCounter = 0;
byte midiClockBeats = 0;
byte seqPositionPrev = 0;
byte seqCounterPrev = 0;
byte variationPrev = 0;
byte midiClockBeatsPrev = 0;
byte ignoreButtons = false;
byte lastVelocity = B00000011;
bool editingNote = false;
byte editStep = 0;
byte editVariation = 0;
byte prevPlayedNote[NOTE_TRACKS];
byte menuPosition = 0;
byte initMode = 0;
char flashHeader[8];
byte receivingExternalSysEx = false;
uint32_t prevMuteTrack = 0;
byte totalFlashErrors = 0;
byte midiInputStage = 0;
byte midiInputBuffer[2] = {0, 0};
byte midiOutputBuffer[3][(DRUM_TRACKS + NOTE_TRACKS) * 3];
byte midiOutputBufferPosition = 0;
byte calculateSequencer = 0;
char editingNoteTranspose = -127;
bool noteTransposeWasChanged = false;
bool noteTransposeEditAllSteps = false;
byte leftLEDsVarSeq = 0;
byte leftLEDsVarSeqBuffer = 0;
uint16_t chaseLEDs[2] = {0, 0};
uint16_t chaseLEDsBuffer[2] = {0, 0};
byte stepVelocity = 0;
byte noteStepGlideDoubleOff = 0;
bool ignoreNextButton = false;
byte showTemporaryMessage = 0;
byte temporaryMessageCounter = 0;
byte xm = 0;
byte inputByte = 0;
byte sendCCCurrentValue[DRUM_TRACKS+NOTE_TRACKS];
byte sendCCCurrentPosition[DRUM_TRACKS+NOTE_TRACKS]; // 0 to 127 and the bit 8 is to know if its going up or down //
byte noteLenCounters[DRUM_TRACKS+NOTE_TRACKS];
byte tickOutCounter = 0;
byte tickOutCounterLen = 0;
bool tickOutPinState = false;
bool isSelectingBank = false;
bool showVersion = true;
byte trackPosition[DRUM_TRACKS + NOTE_TRACKS];
byte* pointerData;
bool patternHasChanges = false;
#if RECORD_ENABLED_ECHO
  bool lateSequencerTick = false;
  bool isSendingMIDIEcho = false;
#endif
#if TRACK_DEBUG_MIDI
  byte lastMIDIinput[4] = {0, 0, 0, 0};
#endif
#if DEBUG_MIDI_INPUT
  byte midiInput[DEBUG_MIDI_BUFFER_SIZE];
  int midiInputItens = 0;
  int midiInputItensEditPos = 0;
  bool midiInputShowHex = true;
#endif
bool recordEnabled = false;
byte recordBuffer[3][MIDI_INPUT_BUFFER];
byte recordBufferPosition = 0;
byte echoCounter[ECHOS][2];
byte echoVelocity[ECHOS];
char echoTrack[ECHOS];
char echoAttackDecay[ECHOS];
byte echoSpace[ECHOS];
byte echoNote[ECHOS];
byte echoEdit = 0;
struct WECHO
{
  byte track, ticks, space, type;
  char attackDecay;
  void init()
  {
    track = type = 0;
    ticks = 24;
    space = 14;
    attackDecay = 5;
  }
};
struct WSTEPS
{
  byte steps[DRUM_TRACKS]; // steps are stored as 8 bits variations in AABBCCDD format. 2 bits per step per variation. 0~3
  uint16_t stepsDouble[4]; // 16 drum tracks, 4 bits each for the ABCD variations
  byte noteSteps[NOTE_TRACKS][4];
  byte noteStepsExtras[NOTE_TRACKS][2]; // 2 bits packed as ABCD: [0] = Velocity (2 bits) ABCD, [1] = Glide/Double ABCD (2 bits)
  void init()
  {
    memset(steps, 0, sizeof(steps));
    memset(stepsDouble, 0, sizeof(stepsDouble));
    memset(noteSteps, 0, sizeof(noteSteps));
    memset(noteStepsExtras, 0, sizeof(noteStepsExtras));
  }
};
struct WPATTERN //
{
  byte totalVariations;
  byte trackProcessor[DRUM_TRACKS+NOTE_TRACKS];
  byte lastNote[NOTE_TRACKS];
  WECHO echoConfig[ECHOS];
  byte programChange[DRUM_TRACKS+NOTE_TRACKS];
  byte sendCC[DRUM_TRACKS+NOTE_TRACKS];
  byte sendCCValueLFO[DRUM_TRACKS+NOTE_TRACKS]; // stores the value in the first 7 bits, last bit set if its a LFO and the value is the rate instead
  void init()
  {
    for (byte xe=0; xe < ECHOS; xe++) { echoConfig[xe].init(); }
    memset(trackProcessor, 0, sizeof(trackProcessor));
    memset(lastNote, DEFAULT_NOTE, sizeof(lastNote));
    memset(programChange, 0, sizeof(programChange));
    memset(sendCC, 0, sizeof(sendCC));
    memset(sendCCValueLFO, 0, sizeof(sendCCValueLFO));
    totalVariations = 4;
  }
};
struct WCONFIG
{
  byte drumNoteLen[DRUM_TRACKS+NOTE_TRACKS];
  byte trackNote[DRUM_TRACKS];
  byte trackMidiCH[DRUM_TRACKS+NOTE_TRACKS]; // 0~15
  byte trackLen[DRUM_TRACKS+NOTE_TRACKS];
  byte programChangeOffset[DRUM_TRACKS+NOTE_TRACKS];
  byte accentValues[3];
  byte BPM;
  bool seqSyncOut;
  uint32_t muteTrack;
  bool midiClockInternal;
  bool writeProtectFlash;
  byte tickOut;
  byte tickOutLen;
  void init()
  {
    trackNote[0] = 36;
    trackNote[1] = 40;
    trackNote[2] = 42;
    trackNote[3] = 44;
    trackNote[4] = 46;
    trackNote[5] = 48;
    trackNote[6] = 49;
    trackNote[7] = 50;
    trackNote[8] = 51;
    trackNote[9] = 52;
    memset(drumNoteLen, 6, sizeof(drumNoteLen));
    memset(trackMidiCH, (DEFAULT_MIDI_CH-1), sizeof(trackMidiCH));
    memset(trackLen, 16, sizeof(trackLen));
    memset(programChangeOffset, 0, sizeof(programChangeOffset));
    for (xm = 0; xm < NOTE_TRACKS; xm++)
    {
      trackMidiCH[DRUM_TRACKS + xm] = xm;
    }
    tickOut = 2;
    tickOutLen = 2;
    muteTrack = 0;
    BPM = 120;
    seqSyncOut = false;
    accentValues[0] = 80;
    accentValues[1] = 100;
    accentValues[2] = 127;
    writeProtectFlash = false;
    #if EXTERNAL_CLOCK
      midiClockInternal = false;
    #else
      midiClockInternal = true;
    #endif
  }
};
WSTEPS stepsData[STEPS];
WPATTERN patternData;
WCONFIG configData;
#define S_MUTE     B01001000
#define S_UNMUTE   B01100011
#define S_1_       B00110000
#define S_W1       B01100100
#define S_W2       B01010010
#define S_X        B01000100
#define S_R        B01010111
#define S_DASH     B01000000
#define S_S        B01101101
#define S_Y        B01100100
#define S_L        B00111000
#define S_O        B00111111
#define S_U        B00111110
#define S_G        B00111101
#define S_F        B01110001
#define S_o        B01011100
#define S_C        B00111001
#define S_N        B00110111
#define S_E        B01111001
#define S_t        B01010000
#define S_n        B01010100
#define S_K        B01110110
#define S_r        B01010100
#define S_T        B00110001
#define S_d        B01011110
#define S_c        B01011000
#define S_A        B01110111
#define S_b        B01111100
#define S_P        B01110011
#define S_I        B00110000
#define S_H        B01110110
#define S__        B00001000
#define S_DOT      B10000000
const byte stepChars[4] PROGMEM = { B00000000, B00001000, B01010100, B00110111 };
const byte numbers[10] PROGMEM = { B00111111, B00000110, B01011011, B01001111, B01100110, B01101101, B01111101, B00000111, B01111111, B01100111};

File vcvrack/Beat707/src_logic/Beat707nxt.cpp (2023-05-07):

/*
 * 
 * Beat707NXT_BETA2 - Works with 3 x TM1638 boards connected in paralel
 * Created by William Kalfelz @ Beat707 (c) 2018 - http://www.Beat707.com / http://www.Wusik.com / http://www.Kalfelz.com
 * Creative Development by Gert Borovčak
 * 
 * ------------------------------------------------------------------------------------------------------------------------------------------------------------------------------------------------------------------------------------------------
 * 
 *  * 2019 Changes to make
 * 
 *  - Invert the SPI Signal for the new SMD Buffer IC: Frank says: change "SPDR = data;" to "SPDR = data ^ 0xff;" in SPI.h
 *  - just to have it all in one sentence: we have that bank 0 issue, the stuttering when saving, the wish to put mutepage to shift&bpm -, invert lines from atmel to flash
 *  
 * ------------------------------------------------------------------------------------------------------------------------------------------------------------------------------------------------------------------------------------------------
 * 
 *      Nov 20 2018
 *    - Added the Output Pulse Click. Check the Global Menu for the new option. The Click value is in 1/16 steps, and the Len(ght) is in 24-PPQ Ticks. Use the Header A54, any pin should work, as I'm using PORTC on the ATmega328, which holds all Analog Pins (they work as digital pins too).
 * 
 *      Nov 19 2018
 *    - Changed how MIDI CC works. Now you have two options: send a single value when the pattern starts, or LFO mode. This uses much less RAM. When in LFO mode instead of Value you will see Rate, which starts very slowly and goes up to get very fast. So you have 3 options in total: CC value, CC LFO On/Off, CC Single Value or LFO Rate.
 *    - Internal change to the MIDI Output Buffers, to use less RAM.
 *    Version 2
 *    - Added Note Len to DRUM TRACKS. By default it is 1/16, if I'm not mistaken, otherwise play around with the values and let me know which value I should use. Just open the global editor and you will see a new option after Note Number. The number is in ticks. Each step is 6 ticks, so 3 ticks is 1/32 step and 6 ticks is 1/16 step.
 *    Version 3
 *    - Added Note Len to NOTE TRACKS. Also default is 1/16. If you set a long note the note OFF option can stop the note before the actual note time is reached.
 *    - When changing the Program Change of a track, it will send the new value right away.
 *      
 *      Nov 14 2018
 *    - Removed Accent Tracks. By default you get velocity MAX and if you hold Button 5 you can cycle the other velocities.
 *    - Removed some MIDI Processors and left Fade In/Out and Random only.
 *    - Set 10 Drum Tracks and 6 Note Tracks.
 *    - Added Program Change and MIDI CC per track in the global menu. This is sent when a new pattern loads up or when you press play/stop on the sequencer. The MIDI CC you can set a Start and End value. If you want just to set 100 as the value and don't change it overtime, just set Start as 100 and leave the rest untouched. To Glide values you just set Start/End and the Rate value, which should not be zero. There is also the MODE option: Slow or Normal. In Normal mode, for each step it will add the Rate to the Start value, until it reaches the End value. In Slow mode, it will count how many rate-values has passed, and raise the Start value by one or -1 if rate is negative. And finally there's the LFO option for MIDI CC which will go up an down from Start to End and End to Start and repeat until you stop the sequencer.
 *    - Changed the Record behaviour to only record on the current selected track (the onscreen one).
 *    - Updated the Global menu to now show things that are not needed. This goes for the Echo/Delay options when the selected one is OFF, and the same goes for Track MIDI CC, if it's OFF, it won't show the other options until you select a MIDI CC for that track.
 *    - Removed SYSEX support as it will need to be revised and redone.
 *    Version 2
 *    - Reduced memory usage for the Track MIDI CCs.
 *    
 * ------------------------------------------------------------------------------------------------------------------------------------------------------------------------------------------------------------------------------------------------
 * 
 *  List of FUTURE Features Changes (*) Done
 *    - (*) 10 Drum Tracks (no accent track)
 *    - (*) 6 Note Tracks
 *    - 512 Patterns (no pattern bank, but use A B C D ... and 64 patterns per letter)
 *    --------------------
 *    - (*) Output Click (5VCC Gate Out). Gate On every XXX Ticks, duration of XXX Ticks. !!!! If you want, it could play a pulse sound, as we have PWM output that supports that.
 *    - (*) Program Change and CC per track with the option to Glide CC up/down values with a value (+/-). EG: CC Glide +02 every XXX ticks.
 *    - (*) Note Lenght in Ticks.
 *    - (*) Record only the selected track (no record per track option)
 *    - New Flash storage code to use better the flash memory IC, avoiding it getting dead-write-sectors so soon.
 *  
 */

// ------------------------------------------------------------------------------------------------------------------------------------------------------------------------------------------------------------------------------------------------
#include "hardware.h"
#include "declarations.h"
#include "Functions.h"

// ------------------------------------------------------------------------------------------------------------------------------------------------------------------------------------------------------------------------------------------------
byte segments[3][16];
byte leds[3];
byte buttons[4]; // raw button values
byte buttonEvent[4][8];
byte buttonEventWasHolding[4] = {0, 0, 0, 0};
byte buttonIsHolding[8];
byte buttonDownTime[4][8]; // time of the button press
byte variation = 0; // ABCD Variations
char forceVariation = -1;
byte curTrack = 0;
bool updateScreen = true;
byte curLeftScreen = 0;
byte curRightScreen = 0;
byte currentPattern = 0;
byte nextPattern = 0;
byte currentPatternBank = 0;
byte nextPatternBank = 0;
uint16_t patternBitsSelector;
bool mirror = true;
bool somethingClicked = false;
bool somethingHappened = false;
bool forceAccent = false;
bool showBPMdot = false;
bool showBPMdotBuffer = false;
bool seqPlaying = false;
byte seqPosition = 0;
byte seqCounter = 0;
byte midiClockBeats = 0;
byte seqPositionPrev = 0;
byte seqCounterPrev = 0;
byte variationPrev = 0;
byte midiClockBeatsPrev = 0;
bool somethingChangedPattern = false; // if true saves the pattern (steps, double steps, midi processor and variations)
bool somethingChangedConfig = false; // if true saves the config data (BPM, track Note #, track MIDI CC, SeqSyncOut)
bool streamNextPattern = false;
bool loadPatternNow = false;
byte ignoreButtons = false;
byte lastVelocity = 0B00000011;
bool editingNote = false;
byte editStep = 0;
byte editVariation = 0;
byte prevPlayedNote[NOTE_TRACKS + DRUM_TRACKS];
byte menuPosition = 0;
byte initMode = 0;
char flashHeader[8];
byte receivingExternalSysEx = false;
uint32_t prevMuteTrack = 0;
byte totalFlashErrors = 0;
byte prevPatternTotalVariations = 4;
byte midiInputStage = 0;
byte midiInputBuffer[2] = {0, 0};
byte midiOutputBufferDT[3][DRUM_TRACKS * 3];
byte midiOutputBufferNT[3][NOTE_TRACKS * 3];
byte midiOutputBufferDTPosition = 0;
byte midiOutputBufferNTPosition = 0;
byte calculateSequencer = 0;
uint16_t patternPagePos = 0;
uint16_t pagePos = 0;
char editingNoteTranspose = -127;
bool noteTransposeWasChanged = false;
bool noteTransposeEditAllSteps = false;
byte leftLEDsVarSeq = 0;
byte leftLEDsVarSeqBuffer = 0;
uint16_t chaseLEDs[2] = {0, 0};
uint16_t chaseLEDsBuffer[2] = {0, 0};
byte stepVelocity = 0;
byte noteStepGlideDoubleOff = 0;
bool ignoreNextButton = false;
byte currentPlaysPattern = 0;
byte currentPlaysChain = 0;
byte repeatMode = 0;
byte showTemporaryMessage = 0;
byte temporaryMessageCounter = 0;
byte xm = 0;
byte inputByte = 0;
byte sendCCCurrentValue[DRUM_TRACKS+NOTE_TRACKS];
byte sendCCCurrentPosition[DRUM_TRACKS+NOTE_TRACKS]; // 0 to 127 and the bit 8 is to know if its going up or down //
byte noteLenCounters[DRUM_TRACKS+NOTE_TRACKS];
byte tickOutCounter = 0;
byte tickOutCounterLen = 0;
bool tickOutPinState = false;
bool isSelectingBank = false;
//
#if TRACK_DEBUG_MIDI
  byte lastMIDIinput[4] = {0, 0, 0, 0};
#endif
//
#if DEBUG_MIDI_INPUT
  byte midiInput[DEBUG_MIDI_BUFFER_SIZE];
  int midiInputItens = 0;
  int midiInputItensEditPos = 0;
  bool midiInputShowHex = true;
#endif
//
bool recordEnabled = false;
byte recordBuffer[3][MIDI_INPUT_BUFFER];
byte recordBufferPosition = 0;
//
byte echoCounter[ECHOS][2];
byte echoVelocity[ECHOS];
char echoTrack[ECHOS];
char echoAttackDecay[ECHOS];
byte echoSpace[ECHOS];
byte echoNote[ECHOS];
byte echoEdit = 0;

WSTEPS stepsData[STEPS];
WPATTERN patternData;
WCONFIG configData;

byte stepChars[4] = { 0B00000000, 0B00001000, 0B01010100, 0B00110111 };
byte numbers[10] = { 0B00111111, 0B00000110, 0B01011011, 0B01001111, 0B01100110, 0B01101101, 0B01111101, 0B00000111, 0B01111111, 0B01100111};

volatile int OCR1A;



// ------------------------------------------------------------------------------------------------------------------------------------------------------------------------------------------------------------------------------------------------
void setup()
{
  pulseOut(false);
  //
  startMIDIinterface();
  initTM1638();
  reset();
  splashScreen();
  //
  #if SHOW_FREE_RAM
    freeMemory();
    sendScreen();
    waitMs(2000);
  #endif 
  flashInit(false);
  loadPatternBank(0);
  calculateSequencer++;
  //
  setupTimerForExternalMIDISync(!configData.midiClockInternal); 
}

// ------------------------------------------------------------------------------------------------------------------------------------------------------------------------------------------------------------------------------------------------
void loop() 
{
  #if !DEBUG_MIDI_INPUT
    doTickSequencer();
    checkPatternStream();
    readButtons();
    //
    if (editingNoteTranspose != -127 && stepBeenHold() == -2) editingNoteTranspose = -127;
    //
    checkInterface(); 
    //
    if (configData.midiClockInternal) handleMIDIInput();
    if (updateScreen)
    {
      updateScreen = false;
      createScreen(); 
      //
      sendScreen();
    } 
  #else
    debugCheckMIDIInput();
    readButtons();
    debugCheckInterface();
    //
    if (updateScreen)
    {
      updateScreen = false;
      debugCreateScreen();
      //
      sendScreen();
    }
  #endif
}

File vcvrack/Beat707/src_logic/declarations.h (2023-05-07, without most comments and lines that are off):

#define DECLARATIONS_H
#include <string.h>
#include <stdint.h>
#include "hardware.h"
#include "flash.h"
#define DISABLE_FLASH 0       // When set it won't use the external flash ic
#define INTRO_ANIMATION 0     // When set will show a random animation them the product name, version and company name
#define INIT_FLASH_MEMORY 1   // Warning, this will erase the entire flash contents
#define INIT_ENTIRE_FLASH 1   // When selected with the above, the entire flash chip will be erased first. This takes around 20 seconds or less to perform before we can write data to the flash chip. If this is not set, the code will erase the flash chip by sector, which takes a bit more time to perform.
#define SHOW_FREE_RAM 0       // Will show how much RAM is left on the display during initiation
#define DEBUG_SERIAL 0        // Sets the serial output to 9600 bauds and sends some debuging information out.
#define DEBUG_MIDI_INPUT 0    // When set the whole unit will operate only to display midi input messages. You will need to set DRUM_TRACKS and NOTE_TRACKS to 1, as this Debug mode uses a lot of memory to store data. Pressing STOP clears the buffer, and pressing +/- shows next/previous event recorded. Pressing the last button on the right toggles between HEX or normal values for the messages.
#define MIDI_OVER_USB 0       // When set will use 38400 bauds for the Serial interface
#define MIDI_IN_TO_PATTERN 1  // When set it will use any MIDI NOTE Input on the selected MIDI Channel (default 1) to select the next playing pattern. Starting from MIDI_IN_START_NOTE
#define MIDI_IN_START_NOTE 24 // MIDI Input to Pattern Selection Starting Note
#define RECORD_ENABLED_ECHO 1 // Enables the midi thru echo on all input notes
#define RECORD_FORCE_VEL 1    // When set velocity will always be the maximum for note track recording
#define EXTERNAL_CLOCK 0      // When set external clock is set by default
#define EXTERNAL_CONTINUE 0   // When set will use it to continue the sequener clock
#define TRACK_DEBUG_MIDI 0    // When set the code will store the last 4 bytes of MIDI Input Message and show those values when you hold the track selector button (Bt#8 on the left).
#define DEFAULT_NOTE 36       // When adding a new note the default note value for the very first note - Set to 0 so it asks what is the default note everytime you add the first one on a pattern
#define DEFAULT_MIDI_CH 10    // MIDI Channel for all tracks: 1 ~ 16
#define DRUM_TRACKS 10        // This can't go above 16
#define NOTE_TRACKS 6         // This can't go above 8
#define PATTERNS 16           // This can't go above 64
#define PT_BANKS 16           // # of Pattern Banks - should be the MAX that the Winbond chip can take (usually 28)
#define ECHOS 2               // Depends on RAM left, usually can't go above 9
#define STEPS 16              // This can't go above 16
#define TEMPORARY_MESSAGE_TIME 80
#define EXTERNAL_CLOCK_TIMER 3960 // Timer speed used to read the External MIDI Clock - MIDI is 31250 bauds = 3906 bytes per second
#define MIDI_INPUT_BUFFER (4 * 2) // The size of the internal buffer used for recording
#define DEBUG_MIDI_BUFFER_SIZE 512
#define FLASH_CHIPSIZE MB64
#define FLASH_VERSION '2'
#include <Functions.h>
enum
{
  fadeIn = 1, fadeOut, randomVel,
  kButtonNone = 0, kButtonClicked, kButtonHold, kButtonRelease, kButtonReleaseNothingClicked,
  kRightSteps = 0, kRightABCDVariations, kRightTrackSelection, kRightPatternSelection, kRightMenuCopyPaste, kRightMenu, kMuteMenu,
  midiNoteOn = 0x90, midiNoteOff = 0x80, midiCC = 0xB0, midiProgramChange = 0xC0, midiChannels = 16,
  echoTypeOnAllNotes = 0, echoTypeForceMaxVelocity, echoTypeForceLowVelocity,
  midiCCLFO = 7,
  procFadeMin = 4,
  menuFirst = 0,
      menuPtNext = 0,
      menuPtPlays,
      menuPtPlaysChain,
      menuMIDIChannel,
      menuNote,
      menuNoteLen,
      menuAccent1,
      menuAccent2,
      menuAccent3,
      menuVariationsABCD,
      menuProc,
      menuEcho,
      menuEchoTrack,
      menuEchoTicks,
      menuEchoSpace,
      menuEchoAttackDecay,
      menuEchoType,
      menuClockType,
      menuSyncOut,
      menuProtect,
      menuProgramChange,
      menuMIDICC,
      menuMIDICCLFO,
      menuMIDICCValueRate,
      menuPulseOut,
      menuPulseOutLen,
      menuInit,
      menuMIDIinPattern,
        lastMenu = menuMIDIinPattern,
  kLeftMain = 0,
  kMemoryProtectMessage = 0, kPatternRepeatMessage,
  kRepeatModeNormal = 0, kRepeatModeChain, kRepeatModePattern
};
extern byte segments[3][16];
extern byte leds[3];
extern byte buttons[4]; // raw button values
extern byte buttonEvent[4][8];
extern byte buttonEventWasHolding[4];
extern byte buttonIsHolding[8];
extern byte buttonDownTime[4][8]; // time of the button press
extern byte variation; // ABCD Variations
extern char forceVariation;
extern byte curTrack;
extern bool updateScreen;
extern byte curLeftScreen;
extern byte curRightScreen;
extern byte currentPattern;
extern byte nextPattern;
extern byte currentPatternBank;
extern byte nextPatternBank;
extern uint16_t patternBitsSelector;
extern bool mirror;
extern bool somethingClicked;
extern bool somethingHappened;
extern bool forceAccent;
extern bool showBPMdot;
extern bool showBPMdotBuffer;
extern bool seqPlaying;
extern byte seqPosition;
extern byte seqCounter;
extern byte midiClockBeats;
extern byte seqPositionPrev;
extern byte seqCounterPrev;
extern byte variationPrev;
extern byte midiClockBeatsPrev;
extern bool somethingChangedPattern; // if true saves the pattern (steps, double steps, midi processor and variations)
extern bool somethingChangedConfig; // if true saves the config data (BPM, track Note #, track MIDI CC, SeqSyncOut)
extern bool streamNextPattern;
extern bool loadPatternNow;
extern byte ignoreButtons;
extern byte lastVelocity;
extern bool editingNote;
extern byte editStep;
extern byte editVariation;
extern byte prevPlayedNote[NOTE_TRACKS + DRUM_TRACKS];
extern byte menuPosition;
extern byte initMode;
extern char flashHeader[8];
extern byte receivingExternalSysEx;
extern uint32_t prevMuteTrack;
extern byte totalFlashErrors;
extern byte prevPatternTotalVariations;
extern byte midiInputStage;
extern byte midiInputBuffer[2];
extern byte midiOutputBufferDT[3][DRUM_TRACKS * 3];
extern byte midiOutputBufferNT[3][NOTE_TRACKS * 3];
extern byte midiOutputBufferDTPosition;
extern byte midiOutputBufferNTPosition;
extern byte calculateSequencer;
extern uint16_t patternPagePos;
extern uint16_t pagePos;
extern char editingNoteTranspose;
extern bool noteTransposeWasChanged;
extern bool noteTransposeEditAllSteps;
extern byte leftLEDsVarSeq;
extern byte leftLEDsVarSeqBuffer;
extern uint16_t chaseLEDs[2];
extern uint16_t chaseLEDsBuffer[2];
extern byte stepVelocity;
extern byte noteStepGlideDoubleOff;
extern bool ignoreNextButton;
extern byte currentPlaysPattern;
extern byte currentPlaysChain;
extern byte repeatMode;
extern byte showTemporaryMessage;
extern byte temporaryMessageCounter;
extern byte xm;
extern byte inputByte;
extern byte sendCCCurrentValue[DRUM_TRACKS+NOTE_TRACKS];
extern byte sendCCCurrentPosition[DRUM_TRACKS+NOTE_TRACKS]; // 0 to 127 and the bit 8 is to know if its going up or down //
extern byte noteLenCounters[DRUM_TRACKS+NOTE_TRACKS];
extern byte tickOutCounter;
extern byte tickOutCounterLen;
extern bool tickOutPinState;
extern bool isSelectingBank;
#if TRACK_DEBUG_MIDI
extern   byte lastMIDIinput[4];
#endif
#if DEBUG_MIDI_INPUT
extern   byte midiInput[DEBUG_MIDI_BUFFER_SIZE];
extern   int midiInputItens;
extern   int midiInputItensEditPos;
extern   bool midiInputShowHex;
#endif
extern bool recordEnabled;
extern byte recordBuffer[3][MIDI_INPUT_BUFFER];
extern byte recordBufferPosition;
extern byte echoCounter[ECHOS][2];
extern byte echoVelocity[ECHOS];
extern char echoTrack[ECHOS];
extern char echoAttackDecay[ECHOS];
extern byte echoSpace[ECHOS];
extern byte echoNote[ECHOS];
extern byte echoEdit;
struct WECHO
{
  byte track, ticks, space, type;
  char attackDecay;
  void init()
  {
    track = type = 0;
    ticks = 24;
    space = 14;
    attackDecay = 5;
  }
};
struct WSTEPS
{
  byte steps[DRUM_TRACKS]; // steps are stored as 8 bits variations in AABBCCDD format. 2 bits per step per variation. 0~3
  uint16_t stepsDouble[4]; // 16 drum tracks, 4 bits each for the ABCD variations
  byte noteSteps[NOTE_TRACKS][4];
  byte noteStepsExtras[NOTE_TRACKS][2]; // 2 bits packed as ABCD: [0] = Velocity (2 bits) ABCD, [1] = Glide/Double ABCD (2 bits)
  void init()
  {
    memset(steps, 0, sizeof(steps));
    memset(stepsDouble, 0, sizeof(stepsDouble));
    memset(noteSteps, 0, sizeof(noteSteps));
    memset(noteStepsExtras, 0, sizeof(noteStepsExtras));
  }
};
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

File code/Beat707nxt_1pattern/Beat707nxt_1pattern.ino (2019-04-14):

/*
 * 
 * Beat707NXT_1PATTERN (No Flash/External Storage)
 * Created by William Kalfelz @ Beat707 (c) 2019 - http://www.Beat707.com / http://www.Wusik.com / http://www.Kalfelz.com
 * Creative Development by Gert Borovčak
 * 
 * ------------------------------------------------------------------------------------------------------------------------------------------------------------------------------------------------------------------------------------------------
 * 
 *  List of Changes
 *  
 *  V0004 - 04/13/2019
 *    * Added Program Change (PC) Offset to the Global Menu, with two values: starting at 0 or starting at 1. This is set per track.
 *    * Added Save to Internal EEPROM (uses the ATmega328 EEPROM) for all data. It compress the pattern steps to fit things out. Here I used a very simple and fast compression code. It checks for zeros in the data, it counts zeros until it finds a non-zero value. It writes a byte message that is the number of zeros up to 127 zeros. The last bit tells if this is zeros or non-zeros. This way I can save space when storing to EEPROM. The reading happens when you power up the device, and writting is done when you stop the sequencer. If the data haven't changed, nothing is saved. It also shows MEM*** where *** is the memory left in the EEPROM. This can be disabled in the EEPROM file: change #define EEPROM_SHOW_MEM_LEFT to 0
 *    
 *  V0002 - 04/12/2019
 *    * Removed some stuff from the interface that is pattern/bank related.
 *    * Added Track Len to the global menu. Goes from 1 to 16. It will follow the Variations ABCD but crop the track length using the LEN value instead. Default is 16, the whole track (all steps).
 *    
 *  V0001 - 04/11/2019
 *    * Fixed the MIDI Input Echo code so it doesn't conflicts with the sequencer interrupt. Before I start sending the note echo I set a variable that tells the sequencer interrupt to perform after I finish up sending the 3 bytes of MIDI information from the note on/off messages.
 *  
 *  V0000 - 04/11/2019
 *    * Improved the midi buffer output, using a faster code so notes are output faster. The code buffers the next tick of the sequencer ahead of time, so when the time comes to output the notes everything is already set in a buffer that is output quickly. The heavy task of "rendering" the next notes are always done after the current buffer is output to the MIDI interface (UART).
 * 
 *  V0000 - 04/10/2019
 *    * Initial Release: removed all flash and spi code. Didn't update the interface, so it will still show the pattern selector but when trying to change a pattern it will do nothing.
 *  
 * ------------------------------------------------------------------------------------------------------------------------------------------------------------------------------------------------------------------------------------------------
 * 
 */
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

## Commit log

2019-02-15 Initial Arduino Source Code
    The last code been used, with the addition of Pulse Click Out
2019-02-24 3 new buttons and a rotary encoder (ALPS EC12E)
    [beat707.kicad_pcb, beat707.sch, tm1638-module.sch]
2019-02-24 all LEDs changed to through-hole, 3mm
    [beat707.kicad_pcb, tm1638-module.sch]
2019-02-25 Create beat707_layout25Feb.kicad_pcb
    unfinished kicad design. still trying with the layout, finding best position for left/right hand.
    [beat707_layout25Feb.kicad_pcb]
2019-02-25 new version from Gert with changed positions
    [beat707.kicad_pcb, beat707_layout25Feb.kicad_pcb]
2019-02-26 final UI layout
    silkscreen still missing, boardsize too large, spacing on bottom and left edge should be sufficient as guide for final board size
2019-02-26 final UI layout +silkscreen
    basic silkscreen, more to come
    [beat707.kicad_pcb]
2019-03-07 more LEDs, switches and resistors for version encoding
    [beat707.kicad_pcb, beat707.sch, tm1638-module.sch]
2019-03-15 test board for TM1638 and main board finished
    [beat707.sch, level-shifter.sch, tm1638-module.sch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]
2019-03-15 board updated and schematic cleanup
    [beat707.kicad_pcb, beat707.sch, level-shifter.sch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]
2019-03-16 placed switches+leds, unfinished
    [_saved_beat707.sch, button.blend, midi.blend]
2019-03-18 components on pcb sorted, not needed = below
    [_saved_beat707.sch, beat707.kicad_pcb]
2019-03-19 removed unneded files
    [tm1638-test.kicad_pcb]
2019-03-19 3D model for button
    [button.blend]
2019-03-19 making brainboard space
    mute leds moved to 4x4 block upper right (will change leds to come from right side tm1638 for easier routing), added spaces between 4 steps, TM1638 part placement = just a try, brainboard parts not p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
    [beat707.kicad_pcb]
2019-03-20 Update beat707.kicad_pcb
    semi final UI element placement & board size. missing: optional mounting holes (square footprint)
    [beat707.kicad_pcb]
2019-03-25 Update beat707.kicad_pcb
    first try for step silkscreen
    [beat707.kicad_pcb]
2019-03-25 restored deleted files and added all 3D models
    [beat707.kicad_pcb, beat707.sch, button.blend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]
2019-04-06 new FRAM test and TM!638 board cleanups
    [fram-test.kicad_pcb, fram-test.sch, tm1638-test.kicad_pcb]
2019-04-11 Updated MIDI Output Buffer
    Improved the midi buffer output, using a faster code so notes are output faster. The code buffers the next tick of the sequencer ahead of time, so when the time comes to output the notes everything i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
2019-04-11 MIDI Echo Fixed
    Fixed the MIDI Input Echo code so it doesn't conflicts with the sequencer interrupt. Before I start sending the note echo I set a variable that tells the sequencer interrupt to perform after I finish up sending the 3 bytes of MIDI information from the note on/off messages.
    [Beat707nxt_1pattern.ino, MIDI_Input.ino, Sequencer.ino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]
2019-04-12 V0002
    - Removed some stuff from the interface that is pattern/bank related.
    - Added Track Len to the global menu. Goes from 1 to 16. It will follow the Variations ABCD but crop the track length using the LEN value instead. Default is 16, the whole track (all steps).
2019-04-13 V004 (added EEPROM support)
    - Added Program Change (PC) Offset to the Global Menu, with two values: starting at 0 or starting at 1. This is set per track.
    - Added Save to Internal EEPROM (uses the ATmega328 EEPROM) for all data. It compress the pattern steps to fit things out. Here I used a very simple and fast compression code. It checks for zeros in 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
2019-04-13 Added Memory Usage Chart
    [Memory Usage.ods]
2019-04-14 new voltage level translation and ISP header
    [beat707.sch]
2019-04-14 FRAM test board deleted, because already tested on breadboard
    [fram-test.kicad_pcb, fram-test.sch, tm1638-module.sch]
2019-05-04 brain board added, bufixes and final board synchronized with schematic
    [Memory Module.sch, beat707.kicad_pcb, beat707.sch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]
2019-05-04 mounting holes and all parts placed
    [beat707.kicad_pcb]
2019-05-04 mounting holes
    [beat707.sch, tm1638-module.sch]
2019-05-05 5 new menu buttons
    [beat707.kicad_pcb]
2019-05-08 new documentation and minor circuit changes
    [Memory Module.sch, brain-board.sch]
2019-05-08 debug pin
2019-06-06 final component placement and routing
    [Memory Module.sch, beat707.kicad_pcb, beat707.sch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]
2019-06-14 final routed version
    [beat707.kicad_pcb, beat707.sch, tm1638-module.sch]
2021-02-27 changes for new KiCad version, added panel file, and added documentation
    [Memory Module.sch, beat707.kicad_pcb, beat707.sch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]
2021-02-28 interactive BOM
2023-04-29 initial port of the Arduino code to C++
2023-04-30 buttons added
2023-05-07 added flash emulation and fixed buttons
    [Beat707nxt.cpp, Sequencer.cpp, TM1638.cpp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]
2023-05-15 fixed flash and keyboard read speed
    [flash.cpp, flash.h]

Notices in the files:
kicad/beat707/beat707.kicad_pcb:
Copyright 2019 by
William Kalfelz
